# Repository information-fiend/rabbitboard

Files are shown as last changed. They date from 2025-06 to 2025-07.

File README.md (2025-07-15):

<h2 align="center">
 
 rabbitboard
</h2>
&nbsp;

> A 65% mechanical keyboard with a knob and screen. 

After making a macropad, holding it felt like *whoa* i wanna make more. Started designing back in March but finished it cuz of Highway! 

### 📷 Pictures
Screenshot 2025-06-25 at 10 28 07 PM
Screenshot 2025-06-25 at 10 28 33 PM
Screenshot 2025-06-25 at 10 23 50 PM
Screenshot 2025-06-25 at 10 23 29 PM
Screenshot 2025-06-25 at 10 22 30 PM

### BOM
|Qty| Device|	Link	|Cost	|
|---|-----|---|---|
65|	Through-hole 1N4148 Diodes	|[Link](https://www.aliexpress.us/item/3256807621334582.html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)|	$1.05
1	|EC11 Rotary encoders	|[Link](https://www.aliexpress.us/item/3256804721655912.html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)|	$3.85
1	|XIAO nRF52840 BLE	|[Link](https://www.amazon.com/Seeed-Studio-XIAO-nRF52840-Microcontroller/dp/B09T9VVQG7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)|	$16.99
64	|Akko V3 Pro Matcha Green Switches|	[Link](https://www.aliexpress.us/item/3256807480638250.html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)|	$17.56
4	|4.7kΩ resistors|	[Link](https://www.aliexpress.us/item/3256805483786320.html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)|	$0.94
1	|MCP23017 io expander chip	|[Link](https://www.aliexpress.us/item/3256807880535113.html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)|	$2.76
1	|0.96 inch OLED 128X64	|[Link](https://www.aliexpress.us/item/3256806315309280.html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)|	$1.60
1 set|	Keycaps|	[Link](https://www.amazon.com/HITIME-XVX-Keycaps-Dye-Sublimation-Keyboard/dp/B0D72V6FKM?ref_=ast_sto_dp&th=1)| 	$21.99
6	|Gasket foam strips	|[Link](https://www.aliexpress.us/item/3256806077981729.html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)|	$5.49
2	|Plate-mounted stabilizers|	[Link](https://www.aliexpress.us/item/3256809103980221.html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)	|$3.02|
1	|Knob	|[Link](https://www.aliexpress.us/item/3256806828807921.html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)	|$0.99|
1	|PCB|	JLCPCB	|$17.10|
1	|Bottom case	|PCBWay	|$19.80|
1	|Plate	|PCBWay	|$11.61|
1	|Top case	|PCBWay|	$22.96|
|         |   |    | = $147.71

 <p align="center">
  
</p>

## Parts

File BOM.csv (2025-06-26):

Unit Qty | Device | Link | Total
65 | Through-hole 1N4148 Diodes | https://www.aliexpress.us/item/3256807621334582.html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 | $1.05
1 | EC11 Rotary encoders | https://www.aliexpress.us/item/3256804721655912.html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 | $3.85
1 | XIAO nRF52840 BLE | https://www.amazon.com/Seeed-Studio-XIAO-nRF52840-Microcontroller/dp/B09T9VVQG7 | $16.99
64 | Akko V3 Pro Matcha Green Switches | https://www.aliexpress.us/item/3256807480638250.html?pdp_ext_f=%7B%22order%22%3A%22449%22%7D | $17.56
4 | 4.7kΩ resistors | https://www.aliexpress.us/item/3256805483786320.html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 | $0.94
1 | MCP23017 io expander chip | https://www.aliexpress.us/item/3256807880535113.html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 | $2.76
1 | 0.96 inch OLED 128X64 | https://www.aliexpress.us/item/3256806315309280.html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 | $1.60
1 set | Keycaps | https://www.amazon.com/HITIME-XVX-Keycaps-Dye-Sublimation-Keyboard/dp/B0D72V6FKM | $21.99
6 | Gasket foam strips | https://www.aliexpress.us/item/3256806077981729.html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 | $5.49
2 | Plate-mounted stabilizers | https://www.aliexpress.us/item/3256809103980221.html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 | $3.02
1 | Knob | https://www.aliexpress.us/item/3256806828807921.html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 | $0.99
1 | pcb | JLCPCB | $17.10
1 | Bottom case | PCBWay | $19.80
1 | Plate | PCBWay | $11.61
1 | Top case | PCBWay | $22.96
 |  |  | $147.71

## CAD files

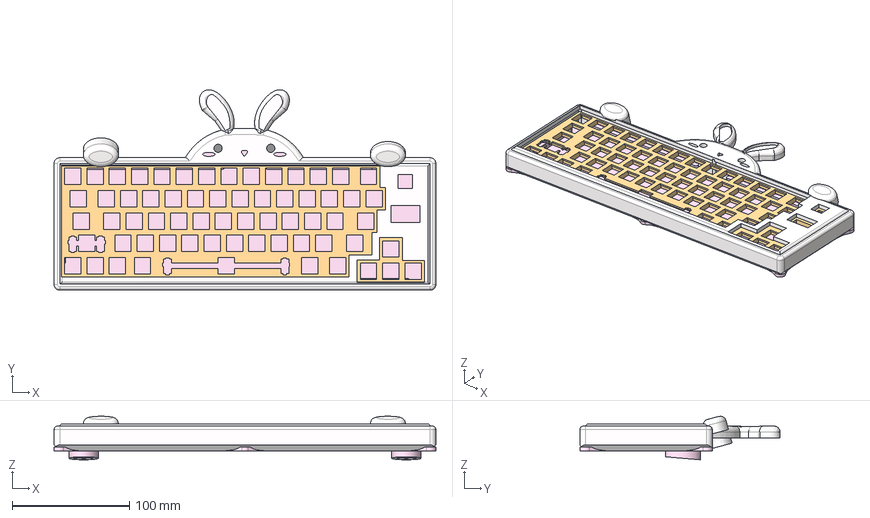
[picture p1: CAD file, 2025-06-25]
CAD/rabbitboard_case v33.step
326.0 x 171.1 x 37.3 mm

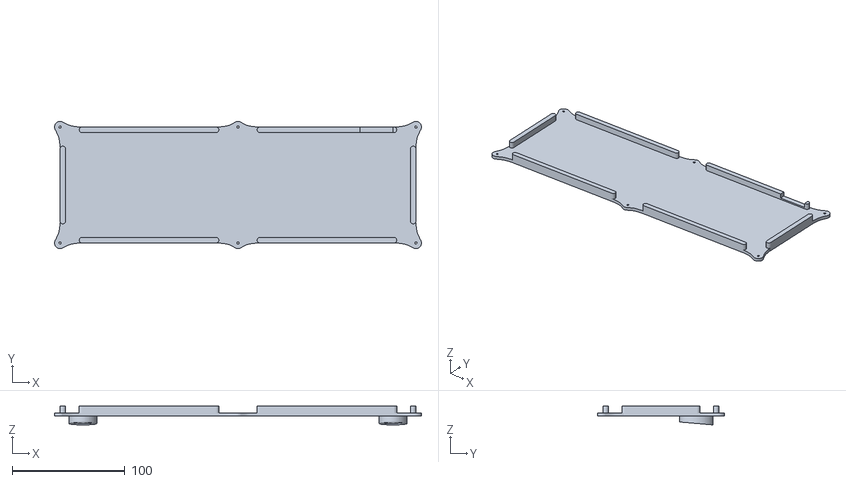
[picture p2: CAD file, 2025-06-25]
Production/Bottom.stl
325.9 x 112.9 x 16.7

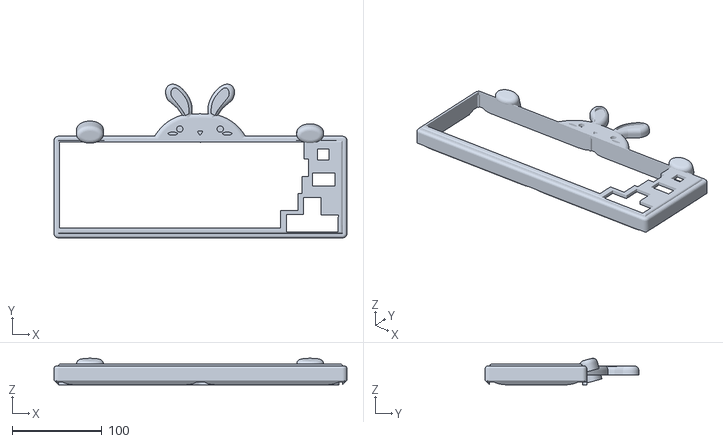
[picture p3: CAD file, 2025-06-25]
Production/Top.stl
326.0 x 171.1 x 29.5

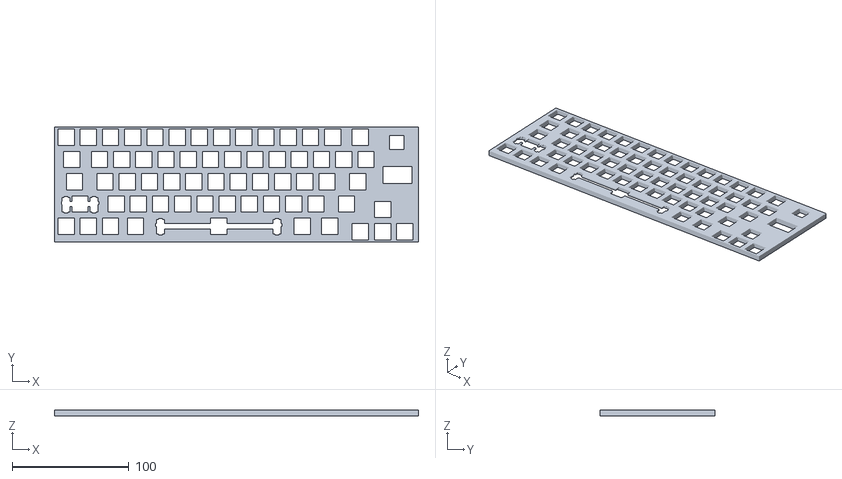
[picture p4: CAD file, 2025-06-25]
Production/Middle.stl
312.3 x 99.0 x 5.00

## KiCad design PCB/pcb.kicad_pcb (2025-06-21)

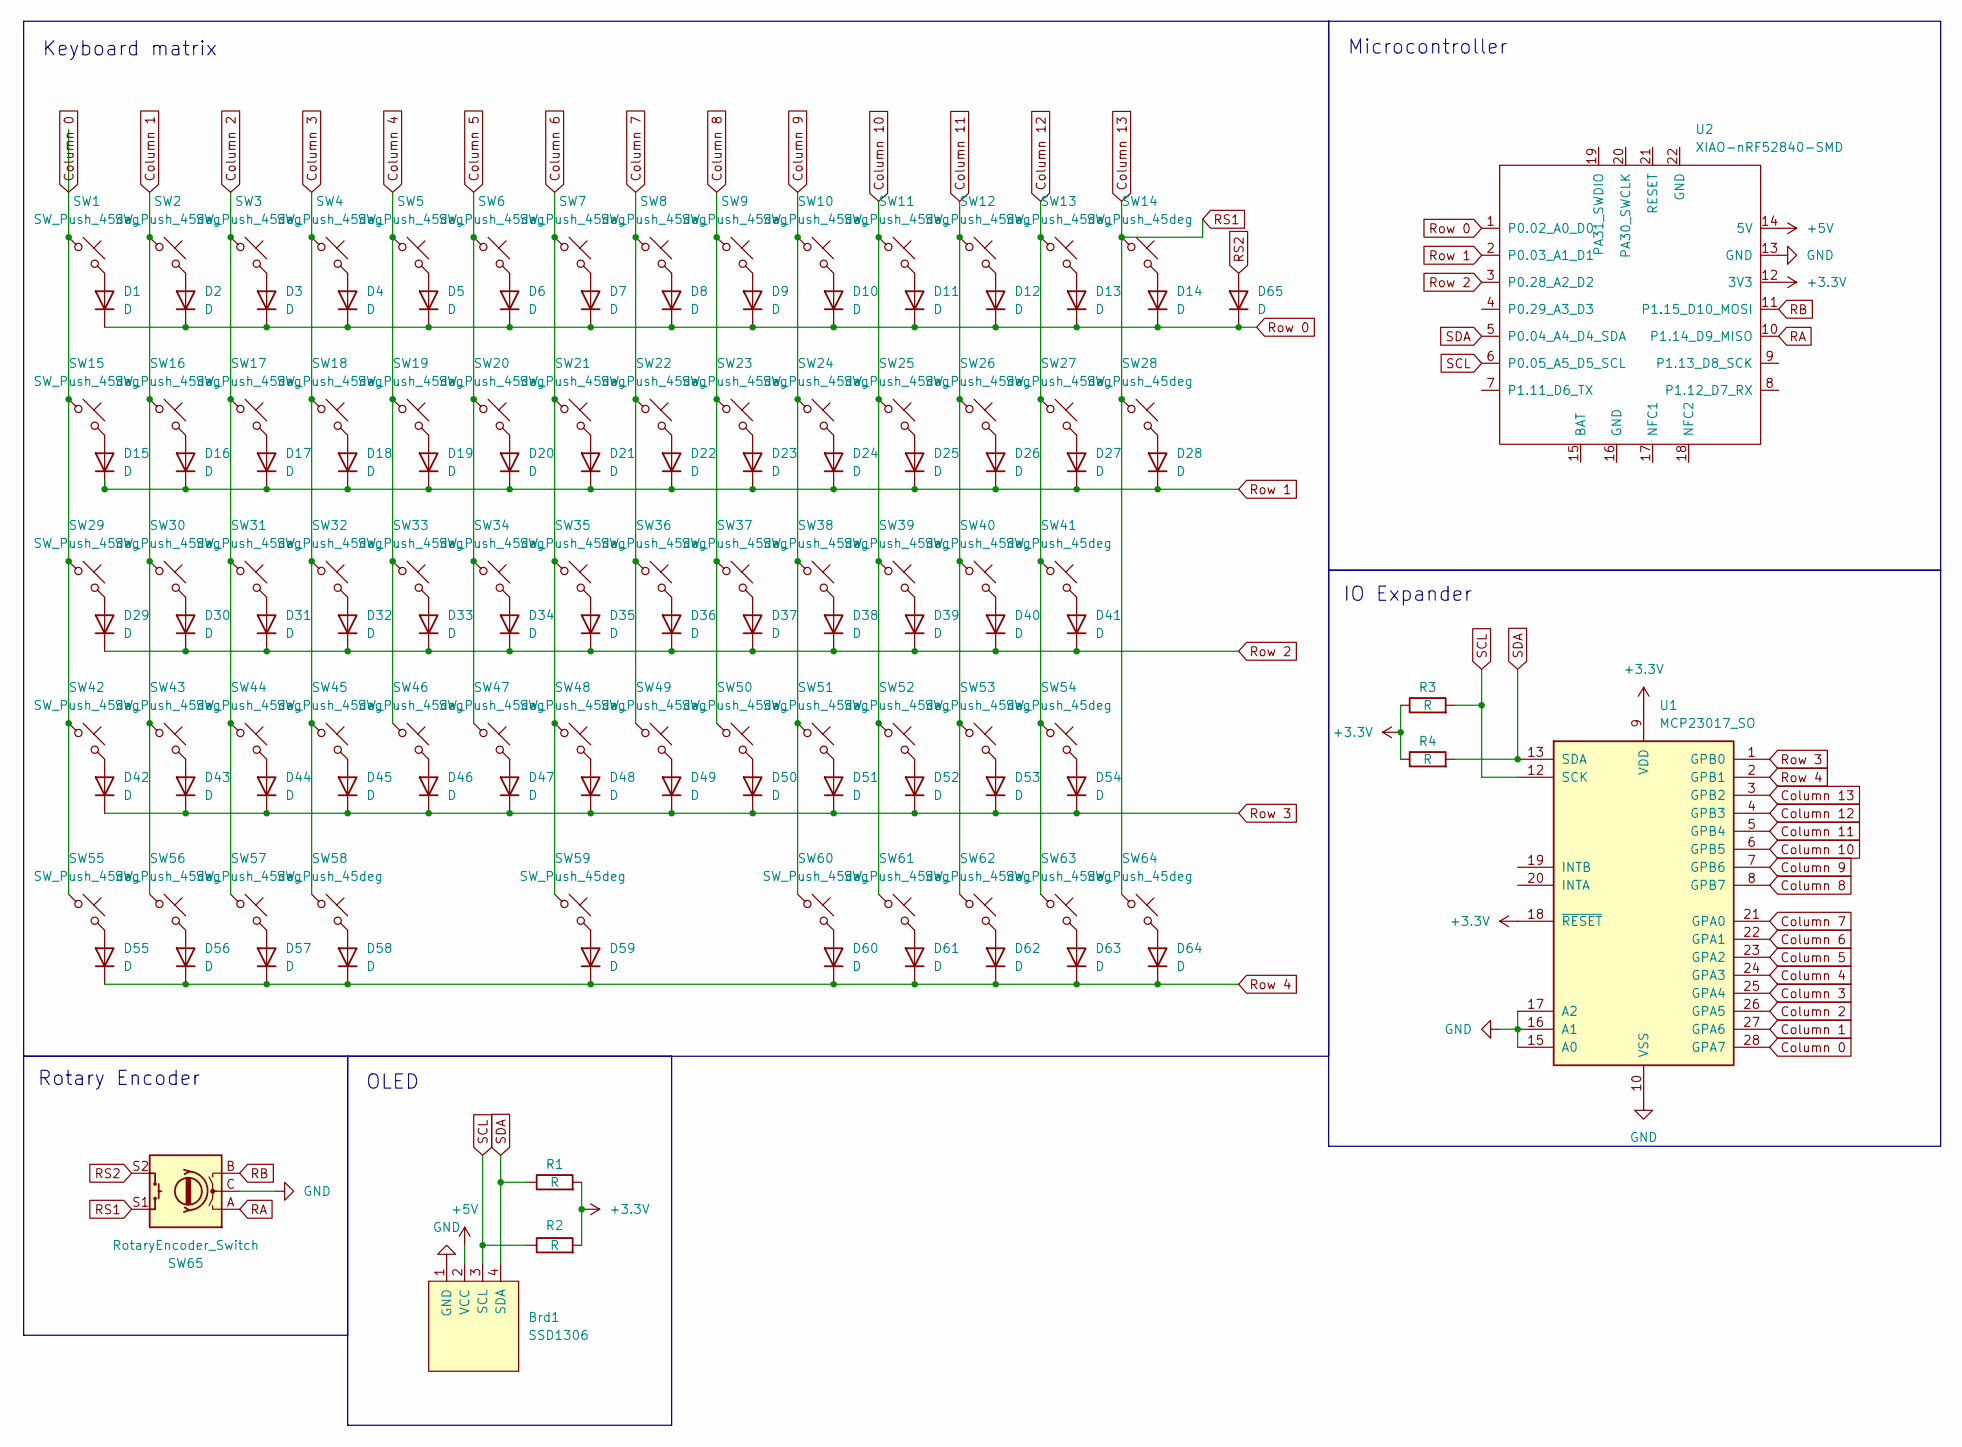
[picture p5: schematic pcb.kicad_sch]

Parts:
Brd1: SSD1306; 128x64OLED
D1, D2, D3, D4, D5, D6, D7, D8, D9, D10, D11, D12, D13, D14, D15, D16, D17, D18, D19, D20, D21, D22, D23, D24, D25, D26, D27, D28, D29, D30, D31, D32, D33, D34, D35, D36, D37, D38, D39, D40, D41, D42, D43, D44, D45, D46, D47, D48, D49, D50, D51, D52, D53, D54, D55, D56, D57, D58, D59, D60, D61, D62, D63, D64, D65: D; D_DO-35_SOD27_P7.62mm_Horizontal
R1, R2, R3, R4: R; R_Axial_DIN0204_L3.6mm_D1.6mm_P7.62mm_Horizontal
SW1, SW2, SW3, SW4, SW5, SW6, SW7, SW8, SW9, SW10, SW11, SW12, SW13, SW14, SW15, SW16, SW17, SW18, SW19, SW20, SW21, SW22, SW23, SW24, SW25, SW26, SW27, SW28, SW29, SW30, SW31, SW32, SW33, SW34, SW35, SW36, SW37, SW38, SW39, SW40, SW41, SW42, SW43, SW44, SW45, SW46, SW47, SW48, SW49, SW50, SW51, SW52, SW53, SW54, SW55, SW56, SW57, SW58, SW59, SW60, SW61, SW62, SW63, SW64: SW_Push_45deg; SW_Cherry_MX_1.00u_PCB
SW65: RotaryEncoder_Switch; RotaryEncoder_Alps_EC11E-Switch_Vertical_H20mm_CircularMoun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
U1: MCP23017_SO; SOIC-28W_7.5x17.9mm_P1.27mm
U2: XIAO-nRF52840-SMD

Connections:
+3.3V: R1.2, R2.2, R3.1, R4.1, U1.9 (VDD), U1.18 (~RESET), U2.12 (3V3)
+5V: Brd1.2 (VCC), U2.14 (5V)
Column 0: SW1.1, SW15.1, SW29.1, SW42.1, SW55.1, U1.28 (GPA7)
Column 1: SW2.1, SW16.1, SW30.1, SW43.1, SW56.1, U1.27 (GPA6)
Column 2: SW3.1, SW17.1, SW31.1, SW44.1, SW57.1, U1.26 (GPA5)
Column 3: SW4.1, SW18.1, SW32.1, SW45.1, SW58.1, U1.25 (GPA4)
Column 4: SW5.1, SW19.1, SW33.1, SW46.1, U1.24 (GPA3)
Column 5: SW6.1, SW20.1, SW34.1, SW47.1, U1.23 (GPA2)
Column 6: SW7.1, SW21.1, SW35.1, SW48.1, SW59.1, U1.22 (GPA1)
Column 7: SW8.1, SW22.1, SW36.1, SW49.1, U1.21 (GPA0)
Column 8: SW9.1, SW23.1, SW37.1, SW50.1, U1.8 (GPB7)
Column 9: SW10.1, SW24.1, SW38.1, SW51.1, SW60.1, U1.7 (GPB6)
Column 10: SW11.1, SW25.1, SW39.1, SW52.1, SW61.1, U1.6 (GPB5)
Column 11: SW12.1, SW26.1, SW40.1, SW53.1, SW62.1, U1.5 (GPB4)
Column 12: SW13.1, SW27.1, SW41.1, SW54.1, SW63.1, U1.4 (GPB3)
Column 13: SW14.1, SW28.1, SW64.1, SW65.S1, U1.3 (GPB2)
GND: Brd1.1 (GND), SW65.C, U1.10 (VSS), U1.15 (A0), U1.16 (A1), U1.17 (A2), U2.13 (GND)
unnamed: D1.2 (A), SW1.2
unnamed: D2.2 (A), SW2.2
unnamed: D3.2 (A), SW3.2
unnamed: D4.2 (A), SW4.2
unnamed: D5.2 (A), SW5.2
unnamed: D6.2 (A), SW6.2
unnamed: D7.2 (A), SW7.2
unnamed: D8.2 (A), SW8.2
unnamed: D9.2 (A), SW9.2
unnamed: D10.2 (A), SW10.2
unnamed: D11.2 (A), SW11.2
unnamed: D12.2 (A), SW12.2
unnamed: D13.2 (A), SW13.2
unnamed: D14.2 (A), SW14.2
unnamed: D15.2 (A), SW15.2
unnamed: D16.2 (A), SW16.2
unnamed: D17.2 (A), SW17.2
unnamed: D18.2 (A), SW18.2
unnamed: D19.2 (A), SW19.2
unnamed: D20.2 (A), SW20.2
unnamed: D21.2 (A), SW21.2
unnamed: D22.2 (A), SW22.2
unnamed: D23.2 (A), SW23.2
unnamed: D24.2 (A), SW24.2
unnamed: D25.2 (A), SW25.2
unnamed: D26.2 (A), SW26.2
unnamed: D27.2 (A), SW27.2
unnamed: D28.2 (A), SW28.2
unnamed: D29.2 (A), SW29.2
unnamed: D30.2 (A), SW30.2
unnamed: D31.2 (A), SW31.2
unnamed: D32.2 (A), SW32.2
unnamed: D33.2 (A), SW33.2
unnamed: D34.2 (A), SW34.2
unnamed: D35.2 (A), SW35.2
unnamed: D36.2 (A), SW36.2
unnamed: D37.2 (A), SW37.2
unnamed: D38.2 (A), SW38.2
unnamed: D39.2 (A), SW39.2
unnamed: D40.2 (A), SW40.2
unnamed: D41.2 (A), SW41.2
unnamed: D42.2 (A), SW42.2
unnamed: D43.2 (A), SW43.2
unnamed: D44.2 (A), SW44.2
unnamed: D45.2 (A), SW45.2
unnamed: D46.2 (A), SW46.2
unnamed: D47.2 (A), SW47.2
unnamed: D48.2 (A), SW48.2
unnamed: D49.2 (A), SW49.2
unnamed: D50.2 (A), SW50.2
unnamed: D51.2 (A), SW51.2
unnamed: D52.2 (A), SW52.2
unnamed: D53.2 (A), SW53.2
unnamed: D54.2 (A), SW54.2
unnamed: D55.2 (A), SW55.2
unnamed: D56.2 (A), SW56.2
unnamed: D57.2 (A), SW57.2
unnamed: D58.2 (A), SW58.2
unnamed: D59.2 (A), SW59.2
unnamed: D60.2 (A), SW60.2
unnamed: D61.2 (A), SW61.2
unnamed: D62.2 (A), SW62.2
unnamed: D63.2 (A), SW63.2
unnamed: D64.2 (A), SW64.2
RA: SW65.A, U2.10 (P1.14_D9_MISO)
RB: SW65.B, U2.11 (P1.15_D10_MOSI)
RS2: D65.2 (A), SW65.S2
Row 0: D1.1 (K), D2.1 (K), D3.1 (K), D4.1 (K), D5.1 (K), D6.1 (K), D7.1 (K), D8.1 (K), D9.1 (K), D10.1 (K), D11.1 (K), D12.1 (K), D13.1 (K), D14.1 (K), D65.1 (K), U2.1 (P0.02_A0_D0)
Row 1: D15.1 (K), D16.1 (K), D17.1 (K), D18.1 (K), D19.1 (K), D20.1 (K), D21.1 (K), D22.1 (K), D23.1 (K), D24.1 (K), D25.1 (K), D26.1 (K), D27.1 (K), D28.1 (K), U2.2 (P0.03_A1_D1)
Row 2: D29.1 (K), D30.1 (K), D31.1 (K), D32.1 (K), D33.1 (K), D34.1 (K), D35.1 (K), D36.1 (K), D37.1 (K), D38.1 (K), D39.1 (K), D40.1 (K), D41.1 (K), U2.3 (P0.28_A2_D2)
Row 3: D42.1 (K), D43.1 (K), D44.1 (K), D45.1 (K), D46.1 (K), D47.1 (K), D48.1 (K), D49.1 (K), D50.1 (K), D51.1 (K), D52.1 (K), D53.1 (K), D54.1 (K), U1.1 (GPB0)
Row 4: D55.1 (K), D56.1 (K), D57.1 (K), D58.1 (K), D59.1 (K), D60.1 (K), D61.1 (K), D62.1 (K), D63.1 (K), D64.1 (K), U1.2 (GPB1)
SCL: Brd1.3 (SCL), R2.1, R3.2, U1.12 (SCK), U2.6 (P0.05_A5_D5_SCL)
SDA: Brd1.4 (SDA), R1.1, R4.2, U1.13 (SDA), U2.5 (P0.04_A4_D4_SDA)

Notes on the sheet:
OLED
Keyboard matrix
Rotary Encoder
IO Expander
Microcontroller

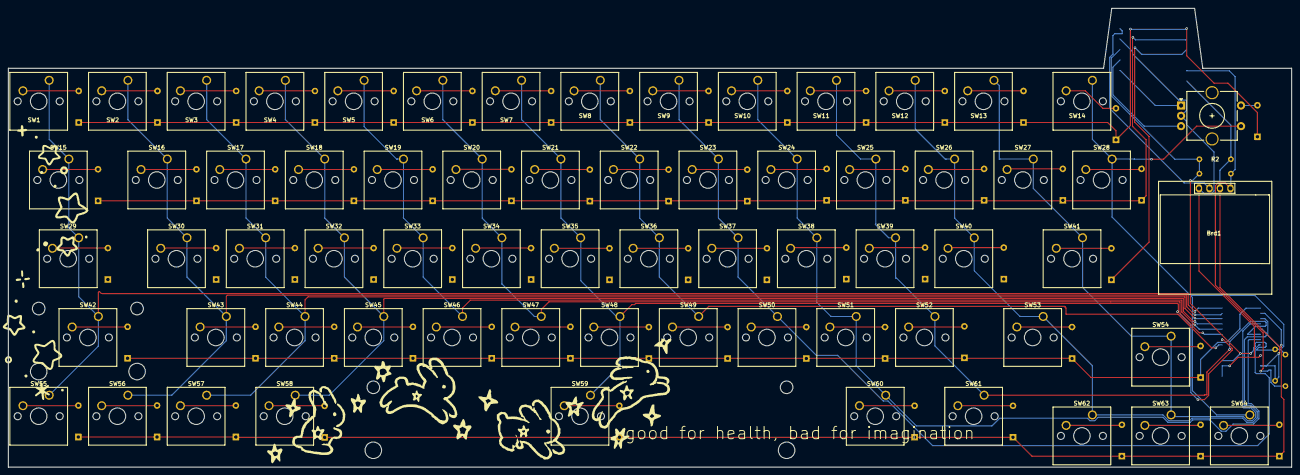
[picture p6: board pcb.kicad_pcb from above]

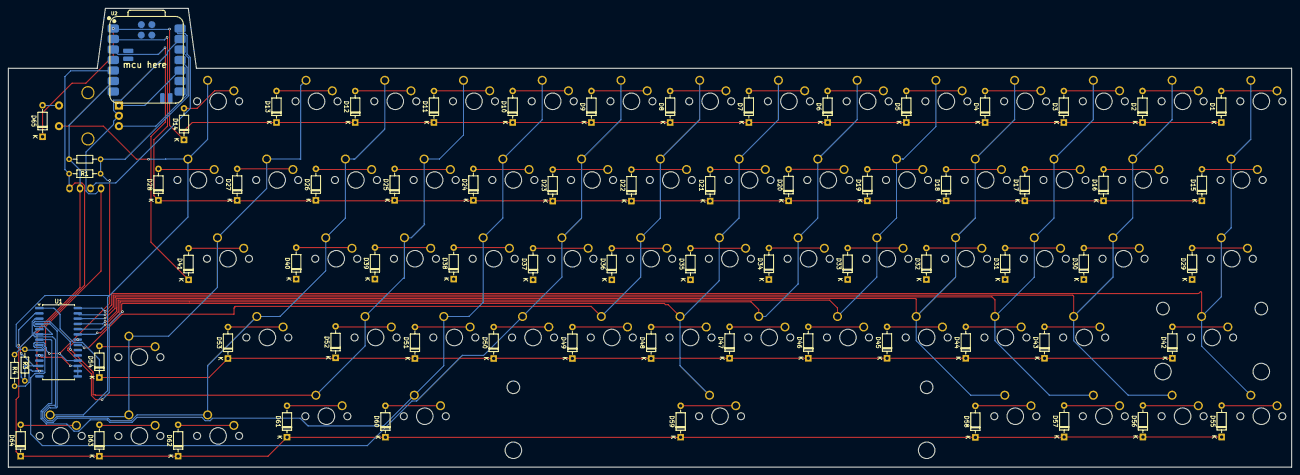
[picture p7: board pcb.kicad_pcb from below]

Board: 2 copper layers, 310.5 x 111.0 mm, 137 parts (71 on the bottom side), 91 nets.

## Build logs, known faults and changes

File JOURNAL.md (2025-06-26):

---
title: "rabbitboard"
author: "info-fiend"
description: "DIY mechanical keyboard, in the shape of a bunny"
created_at: "2025-05-25"
---
### 🐰 Total Time Spent: 57hrs
May 25, 2025
---
*LOG #001:*
started this this back in march, picking it back up. reworked the design and started pcb making  

rabbitpad-v2

TIME SPENT: 1 HOUR

May 27, 2025
---
*LOG #002:* 
finished pcb schematic. it was difficult to figure out what goes where, hopefully works out well 0_0  decided that it can be switched between usb and bluetooth! this took a lot of looking at other people's schematics lol    

TIME SPENT: 4 HOURS

May 28, 2025
---
*LOG #003:*
ohhh gods. i spebt like five hours stressing over the switch placement and looking at 30 different pcbs just to find out there's a plug-in for it, redoing on saturdayyy



TIME SPENT: 5 HOURS

June 1, 2025
---
*LOG #004:* 
i actually dont remember spending this much time on this until i looked at the time. tdy i finished the pcb, ran the checks and it looks good. used the plugin and it made my life 50% easier. routing lowkey had me stressing out, im not sure if its supposed to be so messy. i prolly shoudlnt have spent so long on something like this T_t ---
ADDED cute silkscreen!!! I hope everything with the pcb is done so i can suffer with the case :p

Screenshot 2025-06-01 at 7 42 05 PM
Screenshot 2025-06-01 at 8 40 17 PM

TIME SPENT: 8 HOURS

June 4, 2025
---
*LOG #005:* 
I thought i should update, although i dont have any pictures to show. past few days ive been spending an hour staring at fusion360 and bawling my eyes out. im sooo lost idk where to place the screws, how big the pcb should be, how screws work?!?! i gotta go back to basics i think. heres some of the videos ive been referencing: 
* https://youtu.be/7azQkSu0m_U?si=2aB4zap5jxJfCtVR
* https://youtu.be/iv__343ZwE0?si=1xBRvbvu9lzkbzXI
* https://youtu.be/XKWoeBwpVNg?si=zLpGdxSLkxk3WTyA

TIME SPENT: 3 HOURS

June 8, 2025
---
*LOG #006:* 
i rlly should be working on this more often, wanna finsih this so i can get to other stuff T_T. decided to re-route the pcb and am getting jealous at other people's boards on reddit. ueeerrrggh oh a problem im running into is that the pcb is way too big for the plate.. getting the measurements right is turning out to be v difficult. tears shed: 20.5 

TIME SPENT: 4 HOURS

June 12, 2025
---
*LOG #007:* 
chat im already planning my next project nd i havent even finished this one * sob * gosh oh okay so today i routed the pcb again and its so embarrassing how messy it is. like i hope that it just *works*. then i cried over autofusion, and then i finally figured how i was going to make it!! kinda. i want it to be gasket mounted, and thankfully i dont have to put screws in the pcb for that, but i'd i have to look more into it. there are some really goated YT videos im following and im learnin a lot. i finally extruded the plate to 5mm, part of it is cut by 1.5 so the switches can click. im a little unsure about the top part of the case and how im going to get the exact measurements for the knob and oled. i honestly dont want to touch kicad for the rest of the week lol

Screenshot 2025-06-12 at 8 48 52 PM Screenshot 2025-06-12 at 8 49 11 PM Screenshot 2025-06-12 at 8 49 22 PM

TIME SPENT: 5 HOURS

June 14, 2025
---
*LOG #008:* 
how do i do stuff. cut out stuff for the knob and oled, took a nap (not counted in time lol), made the walls for the case. most of this time was planning how i was even going to build the case. i was going to do a tray mount orginally but wanted it to sound decent. going for a gasket mount. 

Screenshot 2025-06-19 at 1 11 36 PM
Screenshot 2025-06-19 at 1 11 53 PM
Screenshot 2025-06-14 at 9 17 15 PM

TIME SPENT: 5ish HOURS

June 17, 2025
---
*LOG #009:* 
HOW DO SCREWS WORK??? why am i doing math for this seemingly simple design... super confused how im going to do the top part of the case. im thinking of putting the gasket material on the purple things, extend the plate on those edges.. if that makes sense. gonna remake the walls. its very much slowly falling tg. i just wanna be done w this soo i can submitttt.
W video: https://youtu.be/KGMqOSjap68?si=YmXH_uzN2ZAdoxzA

Screenshot 2025-06-19 at 1 28 41 PM
Screenshot 2025-06-19 at 1 28 17 PM
Screenshot 2025-06-19 at 1 27 58 PM

TIME SPENT: 6 HOURS

June 18, 2025
---
*LOG #010:* 
everything lowk went smoothly tdy. spent more time getting the design right before extruding stuff, fusion is getting easier to use. im actually not sure how im going to put the first part of the top part with the other part.. words. uh. bcos i want it to be like different colors?? idk if i have to do technical talk in these journals but i highkey have NO idea what im doing.
to-do:
* fix the screw holes
* put fillets everywhere
* double check meaurements
* put the bunny :D

Screenshot 2025-06-19 at 1 57 21 PM
Screenshot 2025-06-19 at 1 57 39 PM
Screenshot 2025-06-19 at 1 58 27 PM
Screenshot 2025-06-19 at 1 58 43 PM

TIME SPENT: 6 HOURS

June 21, 2025
---
*LOG #011:* 
TO-DO:
* make BOM
* make the QMK (or KMK idk yet)
* upload files for CAD
* contemplate life and my existence in it
* put feet on the bottom of case
* update readme

ngl i dont feel time passing when i work on this, so its weird writing up what i did. its fun looking back at the journal tho!! i came pretty close to redoing the case itself. like reallly close. decided that the plate was just going to sit atop the bottom part instead of being screwed in. the top case had some errors, but i hopefully solved them. i heard someone say when you make a mistake in crochet, it gives it personality. i was applying the same thing here to make myself feel better lol
all i do is yap here, so here's some measurements:
* countersink for screw: 3.6x1.5mm
* screw shaft: 2mm
* height of entire thing: 23mm
* width of bunny head: 104mm

Screenshot 2025-06-21 at 7 16 30 PM
Screenshot 2025-06-21 at 7 17 01 PM
Screenshot 2025-06-21 at 7 17 25 PM

TIME SPENT: 5 HOURS

June 24, 2025
---
*LOG #012:* 
soooooooooo tdy i just made simple firmware. i cant exactly finalize it since KMK requires me to have access to my MCU's drive, so i did it vscode for now. i also made up a BOM, gunna try to finish everything tmrw.
in main.py i put in bluetooth, encoder, and matrix libraries, and an extenstion so i can control the media player from my keyboard. i rlly hope im putting enough info in these logs o_o

Screenshot 2025-06-24 at 7 31 42 PM
Screenshot 2025-06-24 at 7 30 49 PM
Screenshot 2025-06-24 at 7 30 31 PM

TIME SPENT: 3 HOURS

June 25, 2025
---
*LOG: #013:* after submitting...

Screenshot 2025-06-25 at 10 56 36 PM
pure euphoria. 

wrapped up basically everything, mostly finding links for the bill of mats. see you when it gets buillltttttt :)

TIME SPENT: 2 HOURS

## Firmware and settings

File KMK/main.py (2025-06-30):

print("Starting")

import board

#import from kmk library
from kb import KMKKeyboard
from kmk.keys import KC
from kmk.hid import HIDModes
from kmk.modules.encoder import EncoderHandler
from kmk.extensions.media_keys import MediaKeys
keyboard.extensions.append(MediaKeys())

keyboard = KMKKeyboard()

#knobssss
encoder_handler.pins = (
    # regular direction encoder and a button
    (board.GP17, board.GP15, board.GP14)
),

keyboard.keymap = [  # qwerty
        KC.ESC,    KC.N1,     KC.N2,     KC.N3,     KC.N4,     KC.N5,          KC.N6,     KC.N7,     KC.N8,     KC.N9,     KC.N0,     KC.MINS, KC.EQL, KC.BSPACE,
        KC.TAB,   KC.Q,      KC.W,      KC.E,      KC.R,      KC.T,           KC.Y,      KC.U,      KC.I,      KC.O,      KC.P,     KC.LBRC, KC.RBRC, KC.BSLS,
        KC.CAPS,    KC.A,      KC.S,      KC.D,      KC.F,      KC.G,           KC.H,      KC.J,      KC.K,      KC.L,      KC.SCLN,   KC.QUOT, KC.ENT,
        KC.LSFT,   KC.Z,      KC.X,      KC.C,      KC.V,      KC.B,           KC.N,      KC.M,      KC.COMM,   KC.DOT,    KC.SLSH,   KC.RSFT,          KC.UP,
        KC.HOME,   KC.LCTL,    KC.LALT,   KC.LCMD,   KC.SPACE,   KC.RCMD,        KC.RALT,                                                 KC.LEFT, KC.DOWN, KC.RIGHT,
    ],

encoder_handler.map = [
    (KC.VOLD, KC.VOLU, KC.MEDIA_PLAY_PAUSE),
],


if __name__ == '__main__':
    keyboard.go(hid_type=HIDModes.BLE, ble_name='Rabbitboard')

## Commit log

2025-06-21 pcb :D
    [pcb.kicad_pcb, pcb.kicad_sch]
2025-06-24 Create circuitpython
